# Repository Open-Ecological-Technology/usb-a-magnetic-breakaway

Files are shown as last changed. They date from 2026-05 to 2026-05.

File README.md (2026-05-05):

# usb-a-magnetic-breakaway

This repo is for documenting and providing the design requirements for an open-source USB-A magnetic breakaway connector. Originally created to be a solution for BusKill cables. Perhaps you have another reason you want to quickly magnetically detach a USB? Then here's your thing.  This project is a Work In Progress and it welcomes contributors. 

##  What's New?

Updates to goldfishlaser Version:
* Recommend using 4.0 - has latest changes with a new type of pogo receptor
* If continuing to use 3.9 be aware that there are a few issues with it that will need your attention.
* I'm giving a talk at DEF CON! Read about it here: https://crashxblossom.wordpress.com/2024/06/24/defcon32-announcement/ 

## What's in this Repo?

This repo contains full documentation for how to create this gadget. It contains documented 3D print files (SCAD and STL), Bill of Materials, and more. 



Part 1 Video Assembly Instructions: https://youtu.be/HxwEmIUqQ7w?si=xajbAuSA-TxbAlxz
Prototype Assembly Instructions: https://crashxblossom.wordpress.com/2023/07/04/exciting-milestone-in-buskill-usb-a-magnetic-release-open-hardware-project/

#### CAD Files

Directory contains CAD files for the magnetic breakway case if you want to edit the files. *(in development)*

#### STL files

Directory contains 3D print files for the magnetic breakaway case. 

#### Engineering drawings

Directory contains engineering drawings for the magnets which you can provide to a manufacturer for the purpose of ordering the magnets for the magnetic breakway.

#### BOM_4.md

Contains the current BOM. For earlier versions, see Archived BOMs folder.

#### Build 

This folder contains a manual authoring of the unified model in DOF alpha. 

## License

The contents of this repo are dual-licensed. All code is GPLv3 and all other content is CC-BY-SA.

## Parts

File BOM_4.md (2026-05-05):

# V 04 Bill of Materials

**Project:** BusKill USB-A Magnetic Breakaway Connector (open-source laptop kill cord)
**BOM Version:** 4
**Status:** In progress
**Last updated:** 2025-05

---

## Components & Cost

*(Unit costs are single-unit retail prices, without bulk discounts)*

| # | Component | Manufacturer | MPN | Description | QTY | Unit Cost | Subtotal | Supplier | Notes |
| --- | --- | --- | --- | --- | --- | --- | --- | --- | --- |
| 1 | USB male | *(unknown)* | *(unknown)* | Full-size USB-A male connector — spec TBD | 1 | $0.14 | $0.14 | [Amazon](https://amzn.to/43tGNuv) | Part number needed |
| 2 | USB female (10 mm) | *(unknown)* | *(unknown)* | Full-size USB-A female connector, 10 mm — spec TBD | 1 | $0.14 | $0.14 | [Amazon](https://amzn.to/43tGNuv) | Part number needed |
| 3 | Pogo receptors | Mill-Max | 3024-0-01-15-00-00-03-0 | Spring-loaded target contact, flat face, PCB mount | 4 | $0.32 | $1.28 | [Mouser](https://www.mouser.com/ProductDetail/Mill-Max/3024-0-01-15-00-00-03-0?qs=oyhNEzdnFLo7R2sYdNBgsw%3D%3D) | MOQ: 1. Price decreases with quantity; shipping required. |
| 4 | Pogo pins | Mill-Max | 7973-0-15-20-77-14-11-0 | 2.66mm spring-loaded pin, solder cup, through-hole | 4 | $1.13 / $1.27 | $4.52 / $5.08 | [Digikey](https://www.digikey.com/en/products/detail/mill-max-manufacturing-corp/7973-0-15-20-77-14-11-0/10197225) / [Mouser](https://www.mouser.com/ProductDetail/Mill-Max/7973-0-15-20-77-14-11-0?qs=%252B6g0mu59x7KQy9JOdoVaiw%3D%3D) | MOQ: 1. Price decreases with quantity; shipping required. |
| 5 | 3D printed release | *(in-house)* | — | PLA, printed from STL | 1 | — | — | `Goldfishlaser Version/CAD Files/intermediary design files/usbamagb_v04.0.stl` | Material: PLA. Print settings (infill %, layer height) TBD. Combined plastic cost for items 5–6: $8.76 (13.76g / 4.61m filament) |
| 6 | 3D printed breakaway | *(in-house)* | — | PLA, printed from STL | 1 | — | — | `Goldfishlaser Version/CAD Files/intermediary design files/usbamagb_v04.0.stl` | See item 5 for combined cost. |
| 7 | 1/8" cube magnets | K&J Magnetics | B222 | N52 neodymium, 1/8" cube | 8 | $0.18 | $1.44 | [KJ Magnetics](https://www.kjmagnetics.com/proddetail.asp?prod=B222) | MOQ: 1. N52 gold plated variant may perform better. Pull force and operating temp spec TBD. |
| 8 | USB extension cord | *(unknown)* | *(unknown)* | Spec TBD | 1 | $8.00 | $8.00 | *(unknown)* | Supplier and part number needed |
| 9 | Carabiner | *(unknown)* | *(unknown)* | Small keychain-style, anodized aluminum | 1 | $0.80 | $0.80 | *(unknown)* | Retail estimate; bulk pricing ~$0.46/unit (Alibaba). Supplier TBD. |

### Estimated Total Per Unit

| Path | Total |
| --- | --- |
| Digikey (pogo pins) | **$24.32** |
| Mouser (pogo pins) | **$24.88** |

*(Excludes 3D printing cost, which is rolled into plastic line above. Does not include shipping.)*

---

## Alternative & Legacy Vendors

### Pogo Pins

| Prototype Version | Type | MPN | Price/pin | MOQ | Link |
| --- | --- | --- | --- | --- | --- |
| >= v.2.3.9 (current) | 2.66mm spring-loaded, solder cup | Mill-Max 7973-0-15-20-77-14-11-0 | $1.13 (Digikey) / $1.27 (Mouser) | 1 | [Digikey](https://www.digikey.com/en/products/detail/mill-max-manufacturing-corp/7973-0-15-20-77-14-11-0/10197225) / [Mouser](https://www.mouser.com/ProductDetail/Mill-Max/7973-0-15-20-77-14-11-0?qs=%252B6g0mu59x7KQy9JOdoVaiw%3D%3D) |
| =< v.2.3.8 (legacy) | 7.58mm spring-loaded, solder cup | Mill-Max 0947-0-15-20-77-14-11-0 | $0.97 | 1 | [Digikey](https://www.digikey.com/en/products/detail/mill-max-manufacturing-corp/0947-0-15-20-77-14-11-0/7402798) |
| =< v3.9 (legacy) | 3.00mm radius contact pad, 2.00mm height | *(unknown)* | $0.07 | 500 | [Alibaba](https://www.alibaba.com/product-detail/Circular-SMD-Contact-Pad-3-0_62437659039.html) |

### Magnets

**Cube magnets (1/8") — current form factor**

| Prototype Version | Vendor | MPN | Price/magnet | MOQ | Notes | Link |
| --- | --- | --- | --- | --- | --- | --- |
| >= v.3 (current) | K&J Magnetics | B222 | $0.18 | 1 | N52; gold plated variant may be better | [B222](https://www.kjmagnetics.com/proddetail.asp?prod=B222) |
| v.1 (legacy) | Dongguan Hj Tech Co., Ltd. | *(unknown)* | $0.03 | 1000* | Custom shapes. *Vendor accommodated sub-MOQ orders. | [Alibaba](https://www.alibaba.com/product-detail/Hot-Sale-Strong-Electric-Custom-Shape_62489784248.html) |

**Hex magnets — alternative form factor, not used in v4**

| Vendor | Price/magnet | MOQ | Link |
| --- | --- | --- | --- |
| Skyup Magnetics (Ningbo) Co., Ltd. | $0.02–$0.60 | 1 | [Alibaba](https://www.alibaba.com/product-detail/12-Years-Experience-factory-producing-rare_62153270553.html) |
| Xiamen Balin Magnetic Materials Co., Ltd. | $0.05–$0.50 | 1 | [Alibaba](https://www.alibaba.com/product-detail/Powerful-rare-earth-hexagon-neodymium-magnet_62113152666.html) |
| Hangzhou Shengshideng Magnetics Co., Ltd. | $1.00–$10.00 | 1 | [Alibaba](https://www.alibaba.com/product-detail/14-Years-Experience-factory-producing-neodymium_60745639237.html) |

**Disc magnets — ⚠️ DO NOT USE (too weak)**

| Prototype Version | Vendor | Size | Grade | Price/magnet | MOQ | Notes |
| --- | --- | --- | --- | --- | --- | --- |
| =< v.2.3.8 | MANHXSCY | 4×3mm | N35 | $0.08 | 100 | URL no longer active. |
| Not used | MANHXSCY | 5×4mm | N35 | $0.175 | 50 | URL no longer active. |
| — | K&J Magnetics | 1/16" dia. × 1/32" thick | N52 | $0.14 | 100 | [D101-N52](https://www.kjmagnetics.com/proddetail.asp?prod=D101-N52) |

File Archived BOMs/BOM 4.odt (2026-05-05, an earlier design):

V 04 Bill of Materials

Open-source USB-A magnetic breakaway connector used in the BusKill laptop kill cord

This BOM is in progress

Component | Base QTY | Link (if applicable)
USB male | 1 | https://amzn.to/43tGNuv
USB female (10 mm) | 1 | https://amzn.to/43tGNuv
Pogo receptors | 4 | https://www.mouser.com/ProductDetail/Mill-Max/3024-0-01-15-00-00-03-0?qs=oyhNEzdnFLo7R2sYdNBgsw%3D%3D
Pogo pins Working height: | 4 | Option 1: https://www.digikey.com/en/products/detail/mill-max-manufacturing-corp/7973-0-15-20-77-14-11-0/10197225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 Option 2: https://www.mouser.com/ProductDetail/Mill-Max/7973-0-15-20-77-14-11-0?qs=%252B6g0mu59x7KQy9JOdoVaiw%3D%3D
3D printed release | 1 | Goldfishlaser Version/CAD Files/intermediary design files/usbamagb_v04.0.stl
3D printed breakaway | 1 | Goldfishlaser Version/CAD Files/intermediary design files/usbamagb_v04.0.stl
1/8” Cube Magnets | 8 | https://www.kjmagnetics.com/proddetail.asp?prod=B222

Estimated Cost Per Unit (without bulk price discounts)

USB Male = .14

USB female = .14

4 x pogo receptors = 4 x .32

4 x pogo pins = 4 x 1.17 (digikey)

or 4 x 1.27 (mouser)

Plastic = 13.76g / 4.61 meters = $8.76

8 x magnets = 8 x .18

USB Extension cord = $8

USB = $10

caribiner = $.80

Total =

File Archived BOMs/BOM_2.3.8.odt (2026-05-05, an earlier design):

V 2.3.8 Bill of Materials

Open-source USB-A magnetic breakaway connector used in the BusKill laptop kill cord

Component | Base QTY | Link (if applicable)
USB male | 1 | https://amzn.to/43tGNuv
USB female (10 mm) | 1 | https://amzn.to/43tGNuv
Pogo receptors | 4 | https://www.alibaba.com/product-detail/Circular-SMD-Contact-Pad-3-0_62437659039.html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
Pogo pins Working height: 0.298" (7.58mm) | 4 | https://www.digikey.com/en/products/detail/mill-max-manufacturing-corp/0947-0-15-20-77-14-11-0/7402798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
3D printed release | 1 | Goldfishlaser Version/CAD Files/intermediary design files/dengineering_v02.3.8.stl
3D printed breakaway | 1 | Goldfishlaser Version/CAD Files/intermediary design files/dengineering_v02.3.8.stl
3 x 4 mm Disc magnets | 8 | https://www.aliexpress.com/w/wholesale-3x4mm-neodymium-disc-magnets.html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

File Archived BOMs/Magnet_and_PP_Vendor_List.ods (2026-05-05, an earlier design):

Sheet: Magnets
Prototype Version | Name of Vendor | URL of product page | MOQ | Offer sample service? | Price/magnet | Sizes available (if relevant) | Comments
 |  | Cube magnets
Version >= v.3 | K&J Magnets | https://www.kjmagnetics.com/proddetail.asp?prod=B222 | 1 | N/A | 0.18 | 1/8” | Price/magnet decreases with volume size – Latest Prototype uses these – N52 gold plated may be even better
 |  | Disc magnets DO NOT USE TOO WEAK
Version 2 =< v.2.3.8 | MANHXSCY | https://www.aliexpress.us/item/2251832608106847.html | 100 | no | 0.08 | 4x3 | DO NOT USE – TOO WEAK No longer available at URL - 100pcs Neodymium N35 Dia 4mm X 3mm Strong Magnets Tiny Disc NdFeB Rare Earth For Crafts Models Fridge Sticking magnet 4x3mm
Not used | MANHXSCY | https://www.aliexpress.us/item/2251832608138260.html?gatewayAdapt=glo2usa | 50 | no | 0.175 | 5x4 | No longer available at URL - 50pcs Neodymium N35 Dia 5mm X 4mm Strong Magnets Tiny Disc NdFeB Rare Earth For Crafts Models Fridge Sticking magnet 5x4mm
 | K&J Magnets | https://www.kjmagnetics.com/proddetail.asp?prod=D101-N52 | 100 | N/A | 0.14 | 1/16" dia. x 1/32" thick
 |  | Hex magnets
 | Skyup Magnetics (Ningbo) Co., Ltd. | https://www.alibaba.com/product-detail/12-Years-Experience-factory-producing-rare_62153270553.html | 1 | N/A | $0.02-$0.60 | any
 | Xiamen Balin Magnetic Materials Co., Ltd. | https://www.alibaba.com/product-detail/Powerful-rare-earth-hexagon-neodymium-magnet_62113152666.html | 1 | N/A | $0.05 - $0.50 | any
 | Hangzhou Shengshideng Magnetics Co., Ltd. | https://www.alibaba.com/product-detail/14-Years-Experience-factory-producing-neodymium_60745639237.html | 1 | N/A | $1.00 - $10.00 | any
Version 1 | Dongguan Hj Tech Co., Ltd. | https://www.alibaba.com/product-detail/Hot-Sale-Strong-Electric-Custom-Shape_62489784248.html | 1000 | Yes | $0.03 | any | Placed order for 8 magnets of two sizes. September 9, received order October 10 The stated production time is 15-20 days, and the express delivery time is 7-9 days. There was a small delay, possibly due to holiday. (oops – didn’t realize this shop had a MoQ of 1000, but the customer service was great, and the person I worked with says I and others can order lower quantities if desired)

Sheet: Pogo Pins
Prototype Version | URL of product page | MOQ | Offer sample service? | Price/pin | Type | Comments
Version >= v.2.3.9 | https://www.digikey.com/en/products/detail/mill-max-manufacturing-corp/7973-0-15-20-77-14-11-0/10197225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 | 1 | N/A | $1.13 | 2.66mm STANDARD SPRING-LOADED PIN Contact Spring Through Hole, Solder Cup | Price decreases with order quantity; must pay shipping
Version =< v.2.3.8 | https://www.digikey.com/en/products/detail/mill-max-manufacturing-corp/0947-0-15-20-77-14-11-0/7402798 | 1 | N/A | $0.97 | 7.58mmSTANDARD SPRING-LOADED PIN CONTACT SPRING LOADED SLDR CUP | Price decreases with order quantity
Version =<v3.9 | https://www.alibaba.com/product-detail/Circular-SMD-Contact-Pad-3-0_62437659039.html | 500 | yes | $0.07 | 3.00mm radius contact pad, 2.00mm height, target pin | Ordered 11/28/2020 Received 12/16/2020
Version 4.0 | https://www.mouser.com/ProductDetail/Mill-Max/3024-0-01-15-00-00-03-0?qs=oyhNEzdnFLo7R2sYdNBgsw%3D%3D | 1 | N/A | $0.32 | Circuit Board Hardware - PCB Spring-Loaded Target Contact with Flat Face | Price decreases with order quantity; must pay shipping
Version >= v.2.3.9 | https://www.mouser.com/ProductDetail/Mill-Max/7973-0-15-20-77-14-11-0?qs=%252B6g0mu59x7KQy9JOdoVaiw%3D%3D | 1 | N/A | $1.27 | Circuit Board Hardware - PCB Spring-Loaded Pin with Solder Cup Termination | Price decreases with order quantity; must pay shipping

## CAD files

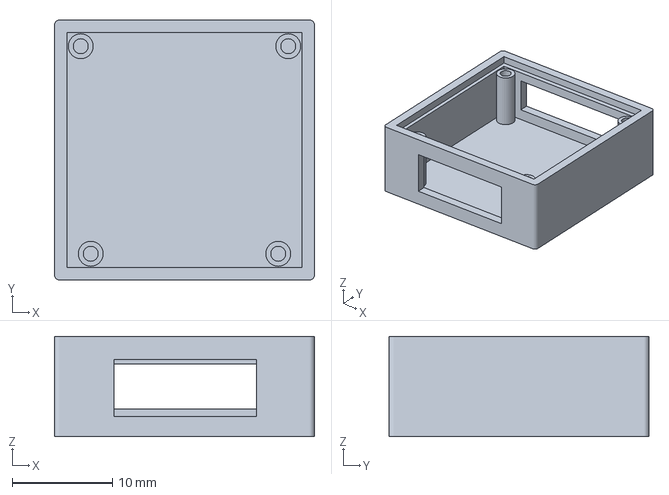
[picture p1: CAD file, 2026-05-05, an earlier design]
CAD Files/FCStd Archive/BusKill_USBA_Breakaway1-Breakaway_Enclosure_Body.3mf
26.0 x 26.0 x 10.0 mm

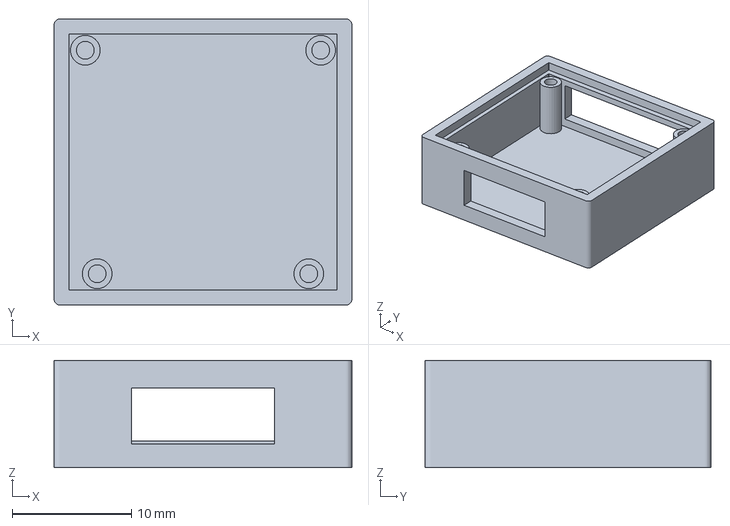
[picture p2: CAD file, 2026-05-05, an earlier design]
CAD Files/FCStd Archive/BusKill_USBA_Breakaway1-Release_Enclosure_Body.3mf
25.0 x 24.0 x 9.00 mm

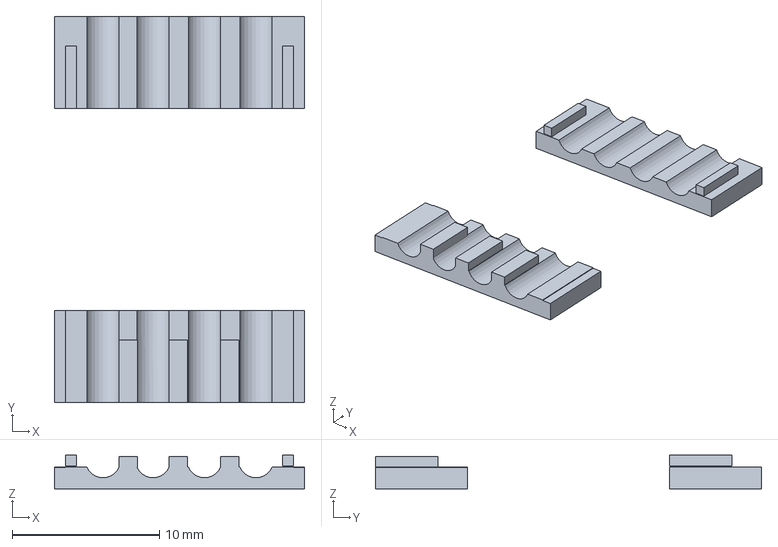
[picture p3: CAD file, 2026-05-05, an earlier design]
CAD Files/FCStd Archive/BusKill_USBA_Breakaway1-Wire_Jig_1.3mf
17.0 x 26.2 x 2.30 mm

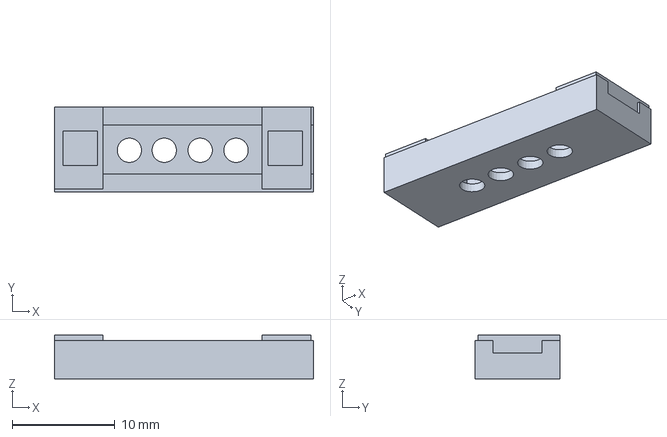
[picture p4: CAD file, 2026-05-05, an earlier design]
CAD Files/FCStd Archive/BusKill_USBA_Breakaway1-Release_Face.3mf
25.2 x 8.25 x 4.25 mm

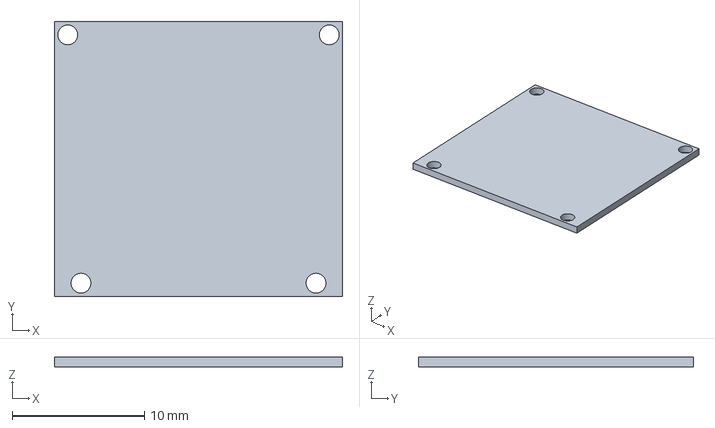
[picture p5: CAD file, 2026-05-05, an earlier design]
CAD Files/FCStd Archive/BusKill_USBA_Breakaway1-Release_Enclosure_Lid.3mf
21.8 x 20.8 x 0.75 mm

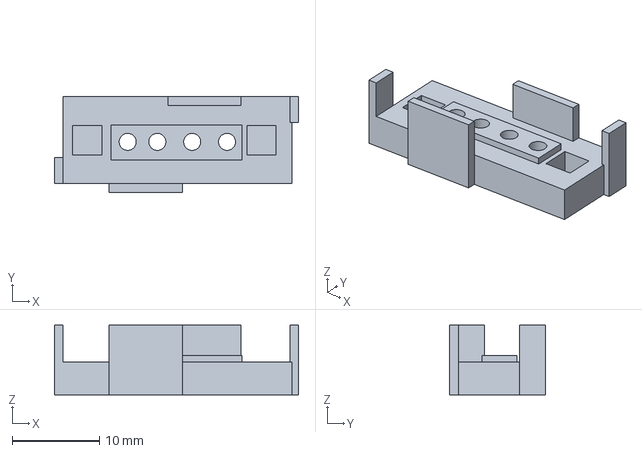
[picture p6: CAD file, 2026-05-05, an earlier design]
CAD Files/FCStd Archive/BusKill_USBA_Breakaway1-Breakaway_Face.3mf
28.0 x 11.0 x 8.00 mm

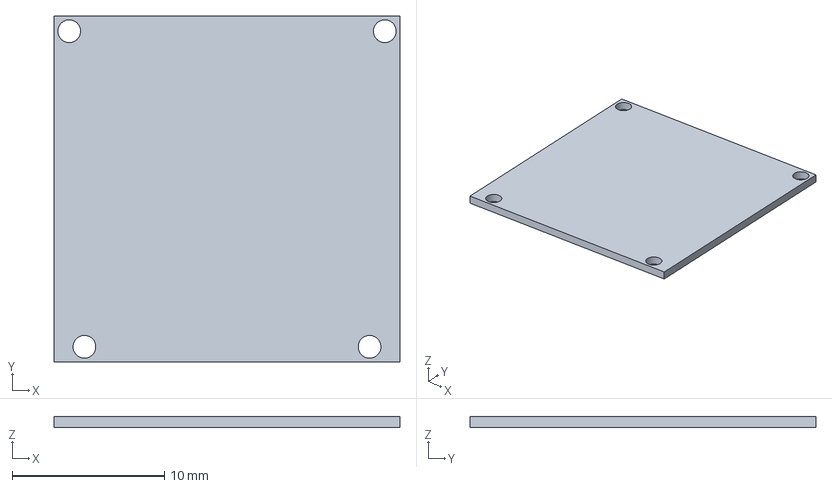
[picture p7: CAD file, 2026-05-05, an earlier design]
CAD Files/FCStd Archive/BusKill_USBA_Breakaway1-Breakaway_Enclosure_Lid.3mf
22.8 x 22.8 x 0.75 mm

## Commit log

2026-05-05 Manually authoring unified model of usb-a magnetic release in dof alpha
2026-05-05 Building out assemblySteps and components of release and breakaway
2026-05-05 Improved BOM.
2026-05-05 archive old vendor list, info is in BOM_4.md now
    [Magnet_and_PP_Vendor_List.ods]
2026-05-05 Adding some svgs and 3mfs y
    [BusKill_USBA_Breakaway1-Breakaway_Enclosure_Body.3mf, BusKill_USBA_Breakaway1-Breakaway_Enclosure_Lid.3mf, BusKill_USBA_Breakaway1-Breakaway_Face.3mf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]
2026-05-05 Add super glue
2026-05-05 add required parts and tools for overall assembly
